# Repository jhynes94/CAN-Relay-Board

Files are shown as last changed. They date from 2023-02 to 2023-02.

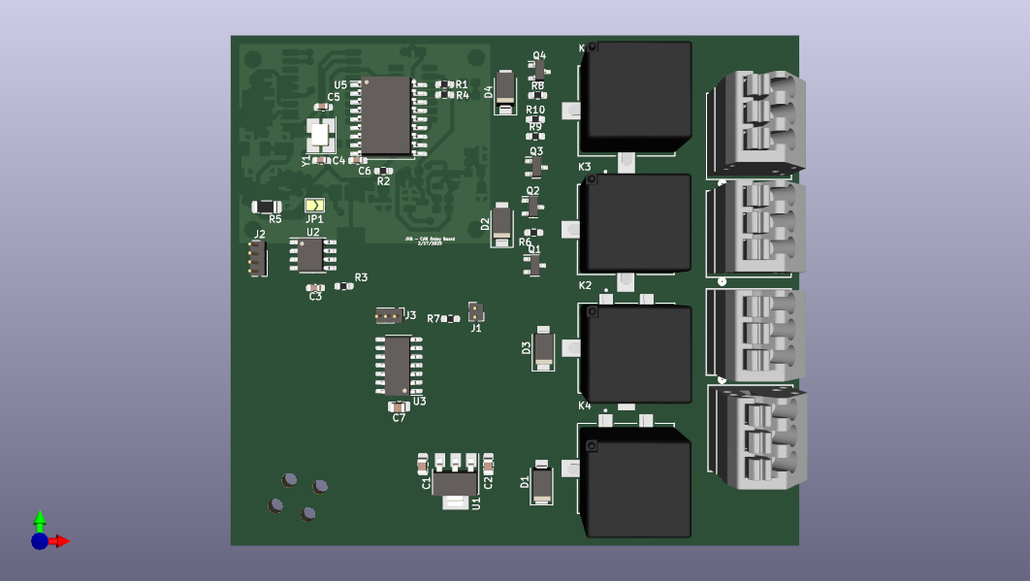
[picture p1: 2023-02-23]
KICAD/Design Review Outputs/2023.02.20/CAN-Relay-Board.png

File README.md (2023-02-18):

# CAN-Relay-Board
CAN controlled Relay board for automotive applications

## Items to complete
1. Detemine Relay to use for design (based on Current(A)/Costs constraints).
2. Design better interface board to use Arduino Nano Programmer
    1. JST Connector to Arduino Development Board
    2. 2.54mm Connector with standard interface board
    3. Consider adding UART connector as well.
3. Determine modes needed for device
    1. CAN ID changing?
    2. CAN Mode changing?
    3. How this should be modified? (DIP swich or via SW)

## Development Setup

Programming the ATTiny is a bit difficult. Setup can be completed using the following tutorial:
https://youtu.be/AL9vK_xMt4E

The library used for SPI enabled CAN device:
https://github.com/autowp/arduino-mcp2515

PEAK CAN usb device is used for interfacing and development. The software to run this is called <b>pcanview<b>

## Far Future items

Future Tutorial for programming an alternative way:
https://www.youtube.com/watch?v=ra7bT74EGUs

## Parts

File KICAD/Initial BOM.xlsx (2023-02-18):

MCU
Microchip | 2.75 | PIC18F25K83T-I/ML | https://www.digikey.com/en/products/detail/microchip-technology/PIC18F25K83T-I-ML/7928139
Microchip | 0.55 | ATTINY202-SSNR | https://www.digikey.com/en/products/detail/microchip-technology/ATTINY202-SSNR/9554944
Microchip | 0.75 | ATTINY414-SSNR | https://www.digikey.com/en/products/detail/microchip-technology/ATTINY414-SSNR/7801796
CAN Controller
Microchip | 2.45 | MCP2515-I/SO | https://www.digikey.com/en/products/detail/microchip-technology/MCP2515-I-SO/593001
Diode
 | 0.16 | BAV99,235 | https://www.digikey.com/en/products/detail/nexperia-usa-inc/BAV99-235/1232158
CAN Transceiver
Supplier | Cost | Part Number | Link
Microchip | 0.8 | MCP2557FDT-H/MNY | https://www.digikey.com/en/products/detail/microchip-technology/MCP2557FDT-H-MNY/6009301
 |  | Competitor | https://www.trombetta.com/products/canopen-devices/
Linear Regulator
 | 0.4 | AZ1117IH-5.0TRG1 | https://www.digikey.com/en/products/detail/diodes-incorporated/AZ1117IH-5-0TRG1/5699673
Op-Amp
 | 0.51 | MCP601T-I/OT | https://www.digikey.com/en/products/detail/microchip-technology/MCP601T-I-OT/418617

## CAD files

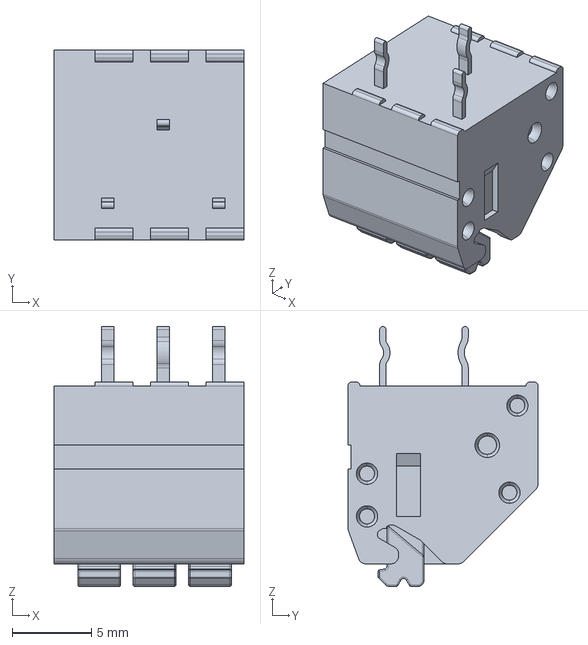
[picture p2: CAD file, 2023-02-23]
KICAD/Custom Components/1-2834011-3/1-2834011-3.step
12.0 x 12.0 x 16.4 mm

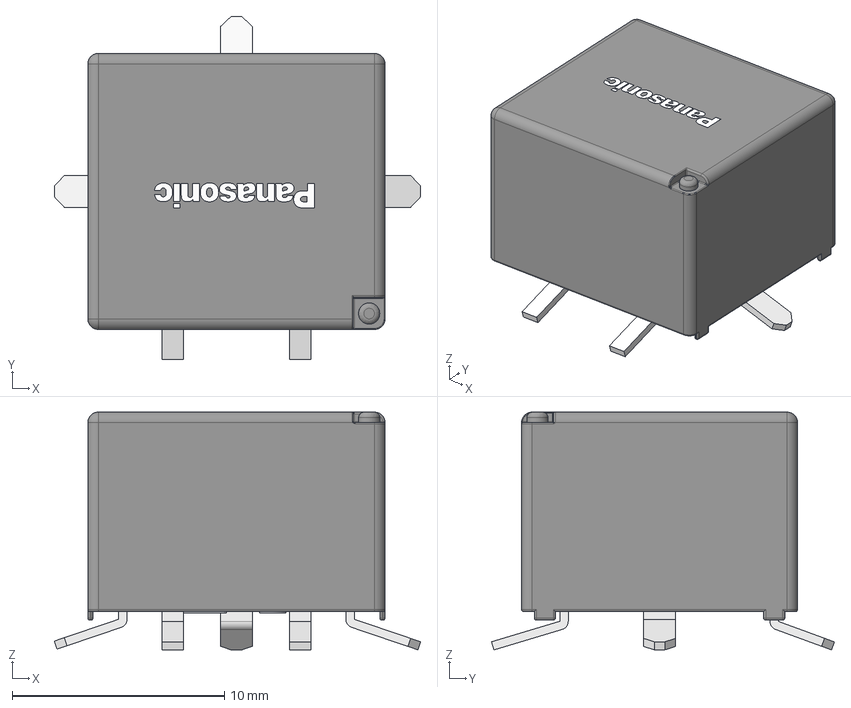
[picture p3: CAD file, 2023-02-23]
KICAD/Custom Components/eec.models/Panasonic_-_CP1SA-12V-X.step
17.3 x 16.2 x 11.2 mm
Relay
Leads
ring
Japan
Panasonic

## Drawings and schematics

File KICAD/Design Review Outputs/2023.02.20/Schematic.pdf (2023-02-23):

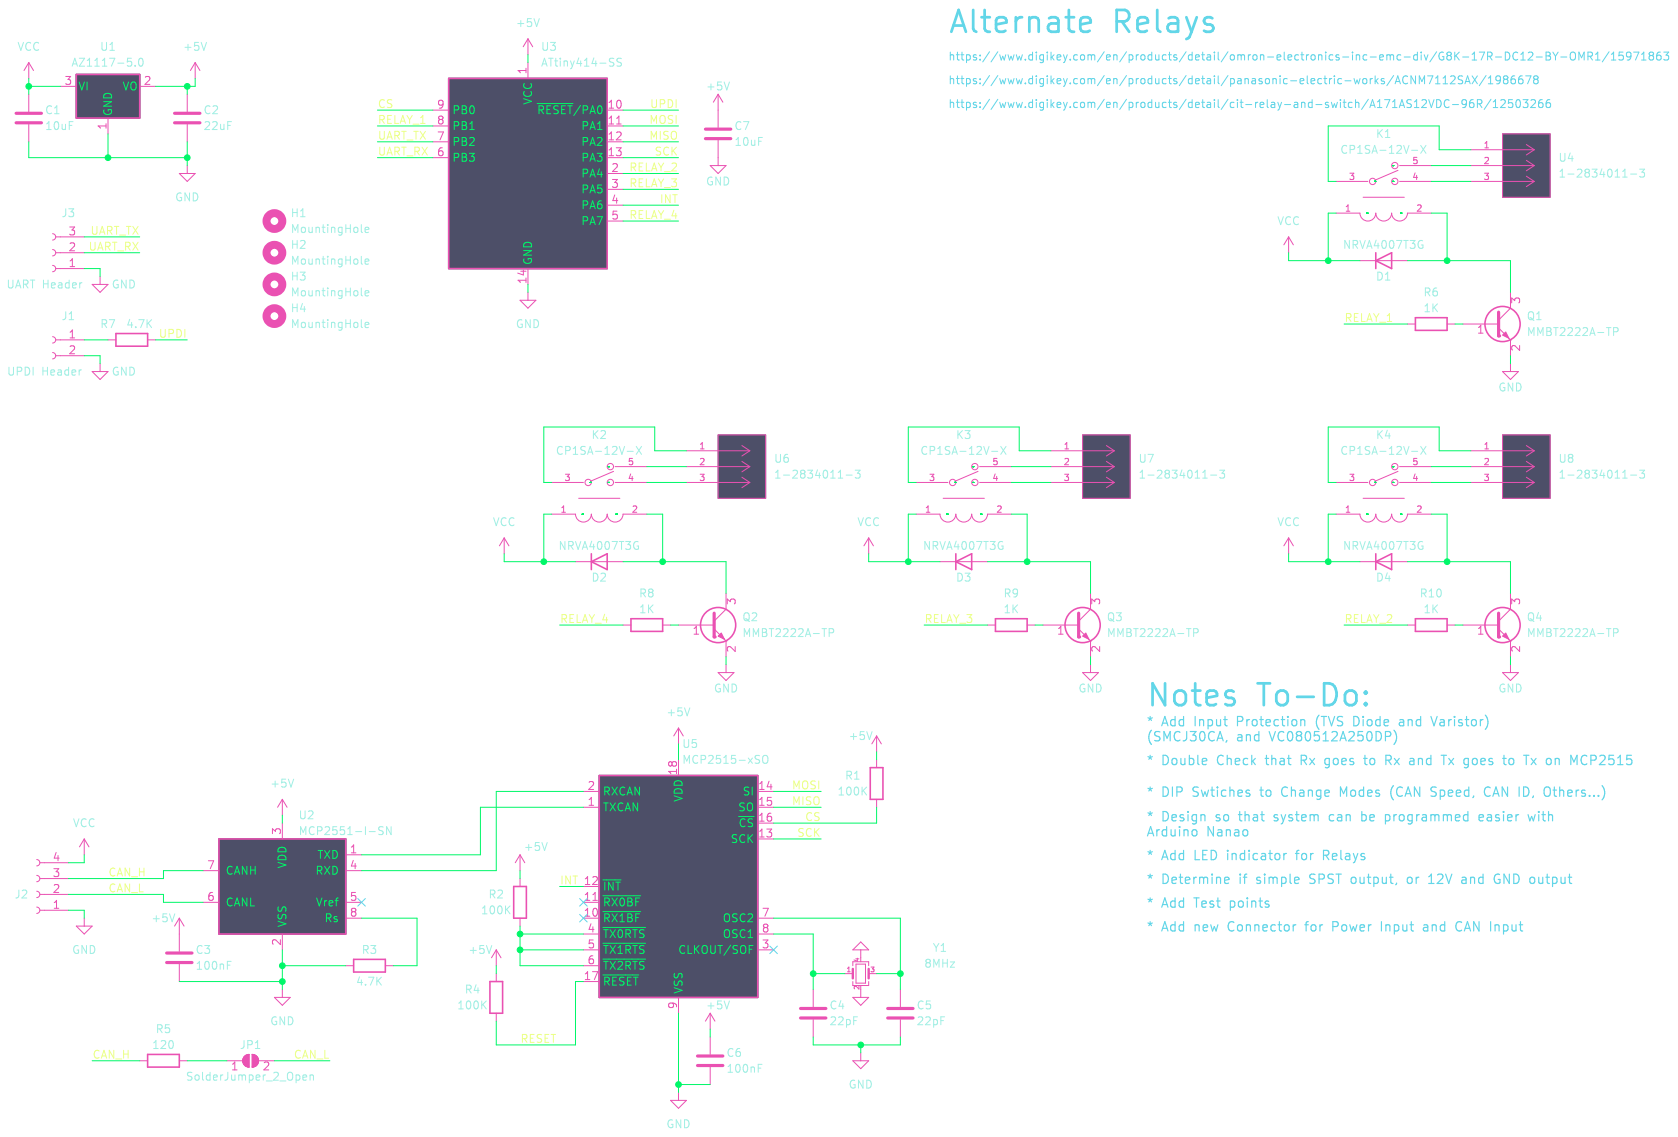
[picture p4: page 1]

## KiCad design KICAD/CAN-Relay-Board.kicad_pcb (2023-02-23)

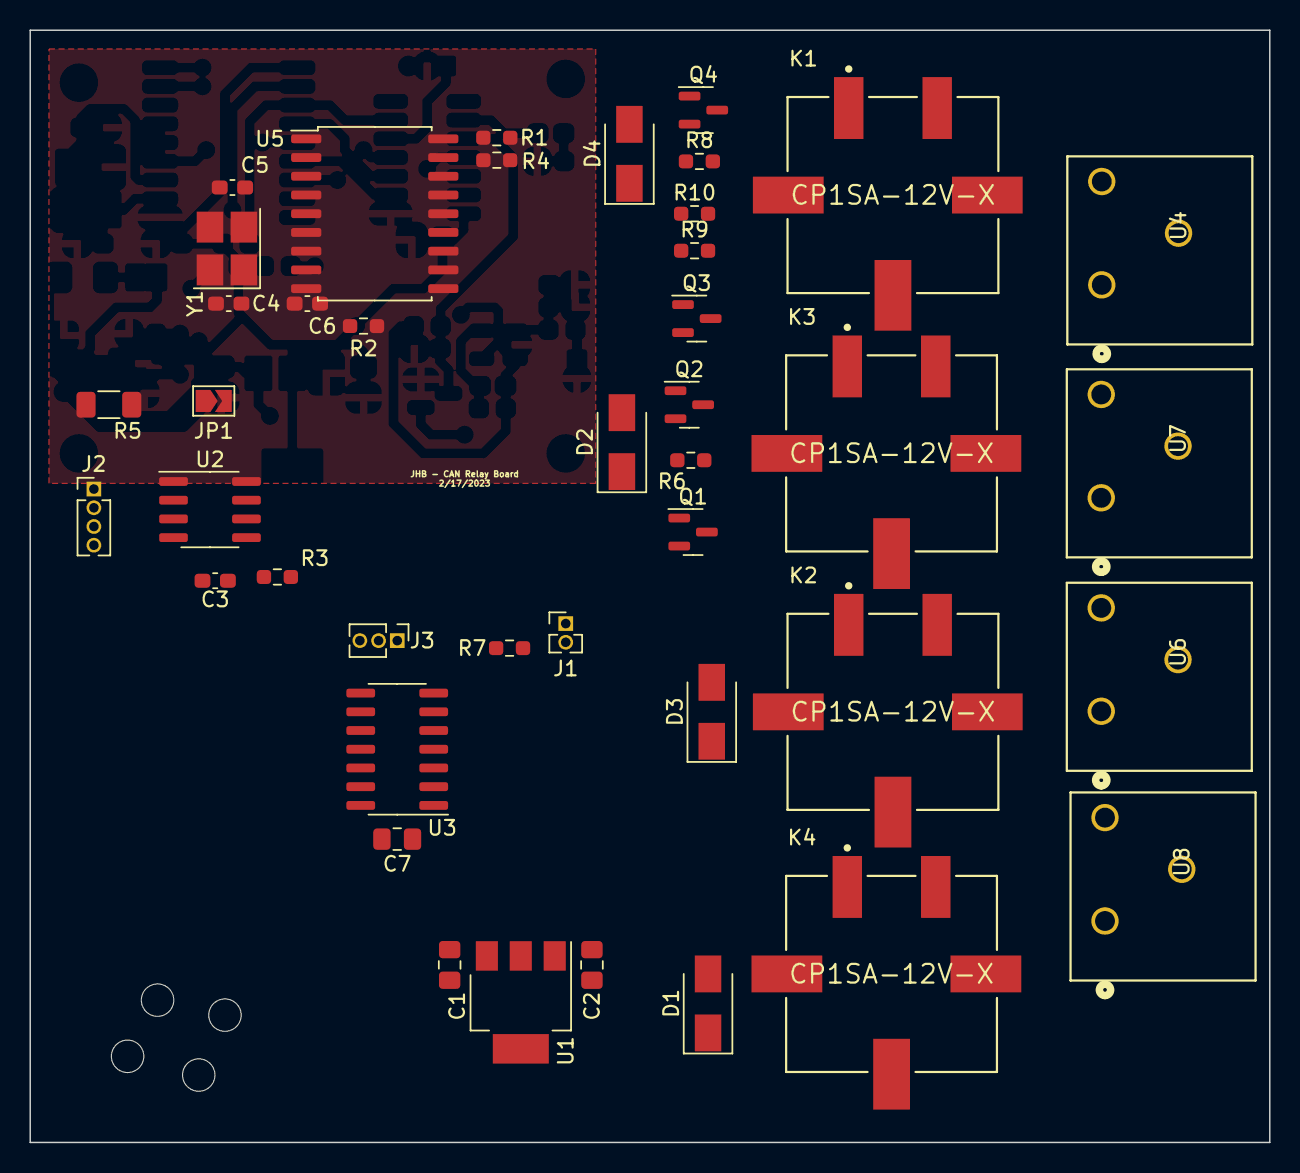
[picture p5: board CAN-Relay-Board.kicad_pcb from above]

Board: 2 copper layers, 84.1 x 75.4 mm, 46 parts (0 on the bottom side), 43 nets, no tracks yet.

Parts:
C1, C7: 10uF; C_0805_2012Metric_Pad1.18x1.45mm_HandSolder
C2: 22uF; C_0805_2012Metric_Pad1.18x1.45mm_HandSolder
C3, C6: 100nF; C_0603_1608Metric_Pad1.08x0.95mm_HandSolder
C4, C5: 22pF; C_0603_1608Metric_Pad1.08x0.95mm_HandSolder
D1, D2, D3, D4: NRVA4007T3G; D_SMA
H1, H2, H3, H4: MountingHole; MountingHole_2.2mm_M2_ISO14580
J1: UPDI Header; PinHeader_1x02_P1.27mm_Vertical
J2: Conn_01x04_Female; PinHeader_1x04_P1.27mm_Vertical
J3: UART Header; PinHeader_1x03_P1.27mm_Vertical
JP1: SolderJumper_2_Open; SolderJumper-2_P1.3mm_Open_TrianglePad1.0x1.5mm
K1, K2, K3, K4: CP1SA-12V-X; Panasonic-CP1SA-12V-X-MFG
Q1, Q2, Q3, Q4: MMBT2222A-TP; SOT-23
R1, R2, R4: 100K; R_0603_1608Metric_Pad0.98x0.95mm_HandSolder
R3, R7: 4.7K; R_0603_1608Metric_Pad0.98x0.95mm_HandSolder
R5: 120; R_1206_3216Metric_Pad1.30x1.75mm_HandSolder
R6, R8, R9, R10: 1K; R_0603_1608Metric_Pad0.98x0.95mm_HandSolder
U1: AZ1117-5.0; SOT-223-3_TabPin2
U2: MCP2551-I-SN; SOIC-8_3.9x4.9mm_P1.27mm
U3: ATtiny414-SS; SOIC-14_3.9x8.7mm_P1.27mm
U4, U6, U7, U8: 1-2834011-3; CONN_1-2834011-3
U5: MCP2515-xSO; SOIC-18W_7.5x11.6mm_P1.27mm
Y1: 8MHz; Crystal_SMD_3225-4Pin_3.2x2.5mm_HandSoldering

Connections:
+5V: C2.1, C3.1, C6.1, C7.1, R1.2, R2.2, R4.2, U1.2 (VO), U2.3 (VDD), U3.1 (VCC), U5.18 (VDD)
/CAN_H: J2.3, R5.1, U2.7 (CANH)
/CAN_L: J2.2, JP1.2 (B), U2.6 (CANL)
/CS: R1.1, U3.9 (PB0), U5.16 (~CS)
/INT: U3.4 (PA6), U5.12 (~INT)
/MISO: U3.12 (PA2), U5.15 (SO)
/MOSI: U3.11 (PA1), U5.14 (SI)
/RELAY_1: R6.1, R8.1, R9.1, R10.1, U3.8 (PB1)
/RESET: R4.1, U5.17 (~RESET)
/SCK: U3.13 (PA3), U5.13 (SCK)
/UART_RX: J3.2, U3.6 (PB3)
/UART_TX: J3.3, U3.7 (PB2)
/UPDI: R7.2, U3.10 (~RESET/PA0)
GND: C1.2, C2.2, C3.2, C4.2, C5.2, C6.2, C7.2, J1.2, J2.1, J3.1, Q1.2 (E), Q2.2 (E), Q3.2 (E), Q4.2 (E), R3.1, U1.1 (GND), U2.2 (VSS), U3.14 (GND), U5.9 (VSS), Y1.2, Y1.4
unnamed: C4.1, U5.8 (OSC1), Y1.1
unnamed: C5.1, U5.7 (OSC2), Y1.3
unnamed: D1.2 (A), K1.2 (2_COIL), Q1.3 (C)
unnamed: D2.2 (A), K2.2 (2_COIL), Q2.3 (C)
unnamed: D3.2 (A), K3.2 (2_COIL), Q3.3 (C)
unnamed: D4.2 (A), K4.2 (2_COIL), Q4.3 (C)
unnamed: J1.1, R7.1
unnamed: JP1.1 (A), R5.2
unnamed: K1.3 (COM), U4.1
unnamed: K1.4 (NO), U4.3
unnamed: K1.5 (NC), U4.2
unnamed: K2.3 (COM), U6.1
unnamed: K2.4 (NO), U6.3
unnamed: K2.5 (NC), U6.2
unnamed: K3.3 (COM), U7.1
unnamed: K3.4 (NO), U7.3
unnamed: K3.5 (NC), U7.2
unnamed: K4.3 (COM), U8.1
unnamed: K4.4 (NO), U8.3
unnamed: K4.5 (NC), U8.2
unnamed: Q1.1 (B), R6.2
unnamed: Q2.1 (B), R8.2
unnamed: Q3.1 (B), R9.2
unnamed: Q4.1 (B), R10.2
unnamed: R2.1, U5.4 (~TX0RTS), U5.5 (~TX1RTS), U5.6 (~TX2RTS)
unnamed: R3.2, U2.8 (Rs)
unnamed: U2.1 (TXD), U5.1 (TXCAN)
unnamed: U2.4 (RXD), U5.2 (RXCAN)
VCC: C1.1, D1.1 (K), D2.1 (K), D3.1 (K), D4.1 (K), J2.4, K1.1 (1_COIL), K2.1 (1_COIL), K3.1 (1_COIL), K4.1 (1_COIL), U1.3 (VI)

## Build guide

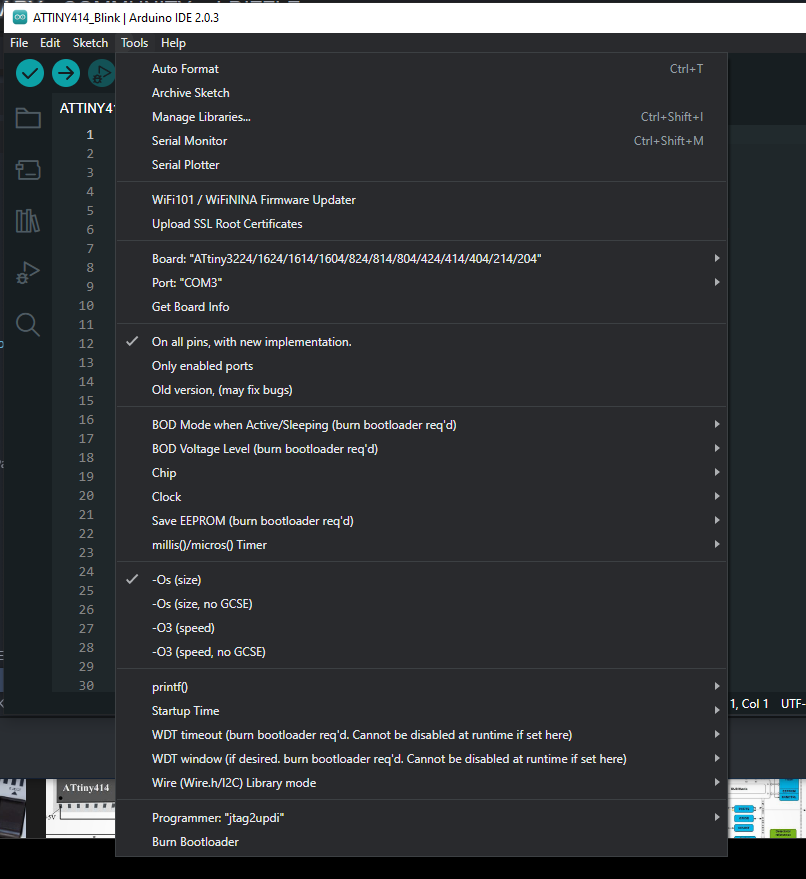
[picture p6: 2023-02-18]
Firmware/How to Program ATTINY414.PNG

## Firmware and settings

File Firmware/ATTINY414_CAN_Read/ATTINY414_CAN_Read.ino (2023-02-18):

#include <SPI.h>
#include <mcp2515.h>

struct can_frame canMsg;
MCP2515 mcp2515(7);


void setup() {
  // Serial.begin(115200);
  
  mcp2515.reset();
  mcp2515.setBitrate(CAN_125KBPS, MCP_8MHZ);
  mcp2515.setNormalMode();
  
  // Serial.println("------- CAN Read ----------");
  // Serial.println("ID  DLC   DATA");
}

void loop() {
  if (mcp2515.readMessage(&canMsg) == MCP2515::ERROR_OK) {

    int LED_pin = 4;
    pinMode(LED_pin, OUTPUT);
    for(int i=0; i<5; i++){
        digitalWrite(LED_pin, HIGH);  // turn the LED on (HIGH is the voltage level)
        delay(100);                      // wait for a second
        digitalWrite(LED_pin, LOW);   // turn the LED off by making the voltage LOW
        delay(100);   
    }
    
    // Serial.print(canMsg.can_id, HEX); // print ID
    // Serial.print(" "); 
    // Serial.print(canMsg.can_dlc, HEX); // print DLC
    // Serial.print(" ");
    
    for (int i = 0; i<canMsg.can_dlc; i++)  {  // print the data
      // Serial.print(canMsg.data[i],HEX);
      // Serial.print(" ");
    }

    // Serial.println();      
  }

}

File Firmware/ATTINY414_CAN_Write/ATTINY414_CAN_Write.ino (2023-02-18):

// Based on https://github.com/autowp/arduino-mcp2515

#include <SPI.h>
#include <mcp2515.h>

struct can_frame canMsg1;
struct can_frame canMsg2;
MCP2515 mcp2515(7);


void setup() {
  canMsg1.can_id  = 0xFF;
  canMsg1.can_dlc = 8;
  canMsg1.data[0] = 0x8E;
  canMsg1.data[1] = 0x87;
  canMsg1.data[2] = 0x32;
  canMsg1.data[3] = 0xFA;
  canMsg1.data[4] = 0x26;
  canMsg1.data[5] = 0x8E;
  canMsg1.data[6] = 0xBE;
  canMsg1.data[7] = 0x86;

  canMsg2.can_id  = 0x036;
  canMsg2.can_dlc = 8;
  canMsg2.data[0] = 0x0E;
  canMsg2.data[1] = 0x00;
  canMsg2.data[2] = 0x00;
  canMsg2.data[3] = 0x08;
  canMsg2.data[4] = 0x01;
  canMsg2.data[5] = 0x00;
  canMsg2.data[6] = 0x00;
  canMsg2.data[7] = 0xA0;
  
}

void printErrorNumberLED(int testError){
  int LED_pin = 4;
  pinMode(LED_pin, OUTPUT);
  for(int i=0; i<testError; i++){
      digitalWrite(LED_pin, HIGH);  // turn the LED on (HIGH is the voltage level)
      delay(300);                      // wait for a second
      digitalWrite(LED_pin, LOW);   // turn the LED off by making the voltage LOW
      delay(300);   
  }
};


void loop() {

  MCP2515::ERROR testError = mcp2515.reset();
  printErrorNumberLED(testError);
  testError = mcp2515.setBitrate(CAN_125KBPS, MCP_8MHZ);
  printErrorNumberLED(testError);
  testError = mcp2515.setNormalMode();
  printErrorNumberLED(testError);
  mcp2515.sendMessage(&canMsg1);
  mcp2515.sendMessage(&canMsg2);

  if (mcp2515.checkError() == true){
    int LED_pin = 4;
    pinMode(LED_pin, OUTPUT);
    for(int i=0; i<5; i++){
        digitalWrite(LED_pin, HIGH);  // turn the LED on (HIGH is the voltage level)
        delay(100);                      // wait for a second
        digitalWrite(LED_pin, LOW);   // turn the LED off by making the voltage LOW
        delay(100);   
    }
    mcp2515.reset();
  }

  
  delay(2000);
}

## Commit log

2023-02-18 Update from alt design for Relay board
    [CAN-Relay-Board.kicad_pcb, CAN-Relay-Board.kicad_sch, Initial BOM.xlsx]
2023-02-23 Schematic 90% complete
    [1-2834011-3.step, CAN-Relay-Board.kicad_pcb, CAN-Relay-Board.kicad_sch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]
